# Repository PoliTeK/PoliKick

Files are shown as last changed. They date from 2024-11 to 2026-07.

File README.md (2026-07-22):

<h1 align="center">
	<br>
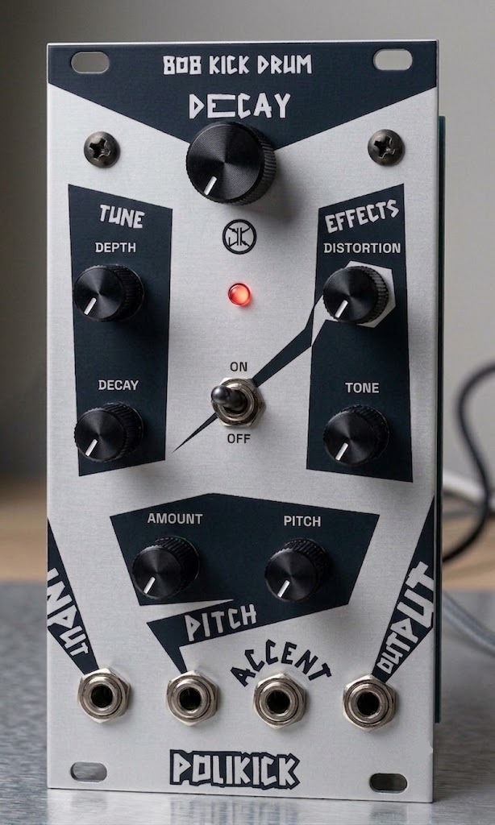
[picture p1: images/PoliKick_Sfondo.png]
		
	<br>
		PoliKicK
	<br>
</h1>

<h4 align="center"> PoliKick is an analog Eurorack kick drum inspired by the legendary <a href="https://en.wikipedia.org/wiki/Roland_TR-808">TR-808</a>. Based on the <a href="https://www.ericasynths.lv/shop/diy-kits-1/edu-diy-kick-drum/">EDU DIY Kick Drum</a> by  <a href="https://www.ericasynths.lv">Erica Synths</a>, it adds a selectable distortion stage and an extended note range.

---

<p align="center">
	<a href="#key-features">Key Features</a> •
	<a href="#list-of-components">List of Components</a> •
	<a href="#how-to-use">How To Use</a> •
	<a href="#credits">Credits</a> •
	<a href="#license">License</a>
</p>

## Key Features

- **Eurorack Standard:** Designed for standard +12V/-12V Eurorack power rails with a 10-pin power header.
- **Trigger and CV Control:** Accepts standard modular trigger pulses (5V-10V) and Control Voltage inputs for dynamic parameter modulation.
- **Authentic Circuitry:** Faithful reproduction of the original analog synthesis paths using modern, easily sourced equivalent components.
- **Expanded Sound Design:** Additional parameters exposed on the front panel compared to the original desktop unit.

## Documentation
The complete design process, simulations, acoustic analysis, crossover calculations, measurements, and construction guide can be found inside the <a href="https://github.com/PoliTeK/PoliKick/tree/NewMain/Documents">**documents**</a> folder included in this repository.

# Project Component List

All the components listed below can be easily found and purchased on major electronic component distributors such as Mouser and DigiKey.

## Resistors

*All resistors are through-hole Metal Film (Part Number: `MFR-25FRF52`)*

| Resistor | Value |
| --- | ----- |
| R1 | 470k  |
| R2 | 4.7k  |
| R3 | 47k |
| R4 | 1M |
| R5 | 100k  |
| R6 | 14k |
| R7 | 33k |
| R8 | 100k  |
| R9 | 100k  |
| R10 | 22k |
| R11 | 120k  |
| R12 | 39k |
| R13 | 100k  |
| R14 | 1k |
| R15 | 1k |
| R16 | 1k |
| R17 | 18k |
| R18 | 1M |
| R19 | 100k  |
| R20 | 10k |
| R21 | 2k |
| R22 | 330 |
| R23 | 10 |
| R24 | 10 |

## Capacitors

| Capacitor | Value | Part Number |
| --- | --- | --- |
| C1 | 15 nF | `MMK5153K50`  |
| C2 | 15 nF | `MMK5153K50`  |
| C3 | 10 nF | `C430C106K3R` |
| C4 | 68 nF | `C320C683J5R` |
| C5 | 5.6 nF  | `MMK5332K50`  |
| C6 | 220 nF  | `MMK5224J50`  |
| C7 | 47 µF | `ESH476M050AG3KA` |
| C8 | 100 nF  | `K104K15X7RF53L2` |
| C9 | 47 µF | `ESH476M050AG3KA` |
| C10 | 100 nF  | `K104K15X7RF53L2` |

## Diodes

| Diode | Characteristics  | Part Number |
| --- | --- | --- |
| D1 - D7 | Small Signal | `1N4148` |
| D8 - D9 | Schottky Barrier | `1N5819` |
| DS1 | Through Hole LED | `LTL-1CHYE` |

## ICs and Transistors

| Component  | Characteristics | Part Number |
| --- | --- | --- |
| U1 | Quad Low-Noise OP Amp | `TL074CN` |
| Q1, Q3, Q4 | NPN Transistor | `BC548B` |
| Q2, Q5 | PNP Transistor | `BC558B` |

## Potentiometers

| Designator | Name | Value | Part Number |
| --- | --- | --- | --- |
| A1 | AmpDeca | 50k, log  | `PTV09A-5025F-A503` |
| A2 | Distortior| 100k, log | `PTV09A-4030F-A104` |
| B1 | Pitch | 100k | `PTV09A-4025F-B104` |
| B2 | Tone | 50k | `PTV09A-4025F-B503` |
| B3 | TuneDeca  | 100k | `PTV09A-4025F-B104` |
| B4 | TuneDept  | 10k | `PTV09A-4025F-B103` |
| B5 | PitchAmo  | 100k | `PTV09A-4025F-B104` |

## Connectors and Switches

| Component | Description | Part Number  |
| --- | --- | --- |
| Connector | Power Header | `TSW-105-07-T` |
| Connector | IC soket | `1-2199298-3`  |
| IN1-Gate | 3.5 mm Stereo Jack | `SJ3-35052B` |
| IN2-AccentCV | 3.5 mm Stereo Jack | `SJ3-35052B` |
| IN3-PitchCV  | 3.5 mm Stereo Jack | `SJ3-35052B` |
| OUT1 | 3.5 mm Stereo Jack | `SJ3-35052B` |
| SW1 | Toggle Switch | `MN12SS4G03` |

## Mechanical Hardware

| Component | Description | Size / Value |
| --- | --- | --- |
| Screws | Machine Screws | M3 |
| Standoffs | Hex Standoffs / Spacers | M3, 1.5cm |

## How To Use

### Hardware Installation

To install the module in your Eurorack system:
1. Ensure your Eurorack case is completely powered off.
2. Connect the 10-pin end of the ribbon cable to the header on the module's PCB. Pay strict attention to the orientation: the **red stripe** on the cable must align with the **-** marking on the PCB.
3. Connect the 16-pin end of the cable to the bus board of your case (red stripe matching -12V).
4. Secure the module to the rails using M3 screws before powering on the case.

### LTspice Simulation

To simulate the analog behavior of the  circuitry, we used LTspice.

- Inside the `Simulation` folder, you will find the `PoliKick.asc` files containing the core voice circuits.
- The trigger inputs in the simulation are modeled using a `PULSE` voltage source configured to  mimick a standard sequencer trigger.
- Run the `.tran` command to observe the envelope generation and the audio output transient response.
- You can adjust the `.step param` commands on the simulated potentiometers to test the range of the front panel controls.

## Credits

Circuit analysis and schematic references based on the [EDU DIY Kick Drum](https://www.ericasynths.lv/shop/diy-kits-1/edu-diy-kick-drum/) by Erica Synths, which originates from the classic Roland TR-808 service manual.

## License

[MIT](https://choosealicense.com/licenses/mit/)

---

<p align="center">
	<a href="mailto:info.politek23@gmail.com">E-Mail</a> •
	<a href="https://www.instagram.com/politek_music">Instagram</a> •
	<a href="https://t.me/+dLKMAwzNmQYxNzM0">Telegram Community</a>
</p>

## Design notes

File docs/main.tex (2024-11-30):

\documentclass{article}

% Useful packages
\usepackage{amsmath}  % improve math presentation
\usepackage{amssymb}
\usepackage{amsthm}
\usepackage[italian]{babel}
\usepackage{cancel}
\usepackage{caption}
\captionsetup{labelfont=bf, font=footnotesize}
\usepackage{circuitikz}
\usepackage{cite} % takes care of citations
\usepackage{enumitem}
\usepackage[final]{hyperref} % adds hyper links inside the generated pdf file
\hypersetup{
	colorlinks=true,       % false: boxed links; true: colored links
	linkcolor=blue,        % color of internal links
	citecolor=blue,        % color of links to bibliography
	filecolor=magenta,     % color of file links
	urlcolor=blue         
}
\usepackage[utf8]{inputenc}
\usepackage[letterpaper,top=2cm,bottom=2cm,left=3cm,right=3cm,marginparwidth=1.75cm]{geometry}
\usepackage{graphicx} % takes care of graphic including machinery
\usepackage{placeins} % better float control
\usepackage{siunitx}
\sisetup{
    sticky-per,
    per-mode=power,
    exponent-product=\cdot,
    forbid-literal-units,
    inline-per-mode=power,
    display-per-mode=fraction,
    uncertainty-mode=separate,
    output-decimal-marker={,}
}
\usepackage{standalone}
\usepackage{subcaption}
\usepackage{tabularx} % extra features for tabular environment

%

\newcommand{\var}[2]{#1_\mathrm{#2}}
\DeclareMathOperator{\ustep}{u}

\theoremstyle{definition}
\newtheorem{example}{Esempio}

%

\title{PoliKick}
\author{Politek}

\begin{document}
\maketitle

\numberwithin{figure}{section}
\numberwithin{equation}{section}

\section{Introduzione}
In questo documento si studia il comportamento dei diversi blocchi che compongono il kick.

\section{Componenti}

\subsection{Gate to Trigger}

\subsubsection{Analisi}
Per cominciare, studiamo il primo blocco del circuito.
La tensione d'ingresso \(v_i\) è un segnale che proviene da un sequencer, pertanto sarà formato da una sequenza di porte rettangolari ("gate").
L'obiettivo di questa sezione è condizionare il segnale in modo che sia utilizzabile dal circuito oscillatore.

\begin{figure}[ht]
    \centering
    \input{circuits/gate_to_trigger.tex}
    \label{fig:gate-to-trigger}
    \caption{Gate to Trigger}
\end{figure}

Ignoriamo inizialmente il diodo. Il segnale \(v_i\) viene immediatamente filtrato da un filtro RC passa-alto, pertanto la tensione \(v_+\) assume la caratteristica forma esponenziale ad ogni transizione di \(v_i\).
È utile introdurre il diodo \(D\) perché alcuni op-amp soffrono di un effetto chiamato "phase inversion" se la tensione ai terminali diventa eccessivamente negativa; il compito del diodo è di bloccare la tensione su \(v_+\) ad un valore fisso durante la fase di discesa del segnale \(v_i\) (figura \ref{fig:gate-to-trigger-condizionamento}).
\\

L'op-amp è nella configurazione di comparatore non invertente senza isteresi:
%
\begin{align*}
    v_o &= \begin{cases}
        +\var{V}{AL}, & v_A > \var{V}{REF} \\
        -\var{V}{AL}, & v_A < \var{V}{REF} \\
    \end{cases}
    &
    \var{V}{REF} &= k \var{V}{AL}
    &
    k \triangleq \frac{R_a}{R_a + R_b}
\end{align*}

La frequenza di taglio del filtro passa-alto è \(f_0 = \frac{1}{2 \pi \tau}\), dove \(\tau = RC\).
Durante il transitorio in fase di salita del segnale \(v_i\), si ha \(v_A > \var{V}{REF}\) solo per un breve intervallo di tempo \(\Delta t\).
In questo intervallo l'uscita del comparatore è \(\var{V}{AL}\).
%
\begin{figure}[htp]
    \centering
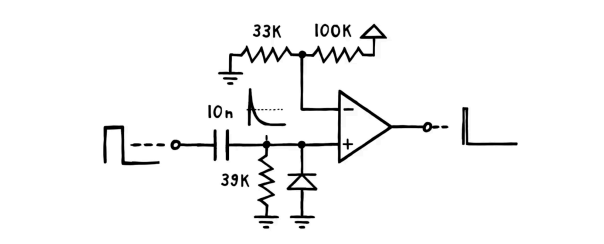
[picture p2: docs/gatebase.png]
     
    \caption{Condizionamento del segnale}
    \label{fig:gate-to-trigger-condizionamento}
\end{figure}
\\
Esaminiamo uno di questi transitori:
\begin{align}
    v_A(t) > \var{V}{REF} & \implies
    V_I e^{-t/\tau} \ustep(t) > \var{V}{REF} = k \var{V}{AL} \geq 0 \nonumber \\
    & \implies 0 < t < \tau \log\frac{V_I}{k \var{V}{AL}} \triangleq \Delta t
    \label{eq:trigger-dt}
\end{align}

Affinché il funzionamento del circuito sia corretto è necessario che l'op-amp abbia uno slew rate sufficientemente alto:
\begin{equation*}
    S_R \gg \frac{2 \var{V}{AL}}{\Delta t}
\end{equation*}

La presenza dell'op-amp garantisce un'impedenza d'uscita \(\var{R}{out} \approx 0\).

\subsubsection{Dimensionamento}
È necessario che la costante di tempo \(\tau\) sia sufficientemente piccola rispetto alla durata \(T\) del gate.
Scegliamo prima il valore di \(\Delta t\), da cui dipende il funzionamento del blocco oscillatore.
Imponiamo quindi \(5 \tau \le T\)

\begin{example}
    Si sceglie \(\Delta t = \tau = T/10\), dunque:
    \begin{align*}
        &\cancel{\tau} \log\frac{V_I}{k \var{V}{AL}} = \cancel{\Delta t} \implies
        V_I = e \cdot k \var{V}{AL} \implies
        k = \frac{R_a}{R_a + R_b} = \frac{V_I}{e \var{V}{AL}} \\
        &\tau = RC \implies C = \tau/R = \frac{T}{10R}
    \end{align*}
\end{example}

\subsection{Accent Control Voltage}

\subsubsection{Analisi}

Il secondo blocco che esamineremo è l'\emph{Accent CV}, che permette di modificare l'entità dell'impulso in uscita dal blocco precedente attraverso una tensione di controllo \(v_A\)
(figura \ref{fig:accent-cv}).
La tensione \(v_A\) assume un valore compreso tra \qty{0}{\volt} e \qty{5}{\volt}. \\

\begin{figure}[ht]
    \centering
    \input{circuits/accent_cv.tex}
    \caption{Accent CV}
    \label{fig:accent-cv}
\end{figure}

Innanzitutto osserviamo che \(T_1\) non può entrare in saturazione perché \(\var{V}{CB,1} = -v_A \le \qty{0}{\volt}\), pertanto la giunzione collettore-base non può essere in conduzione.
Poiché la tensione in ingresso \(v_i\) è la tensione d'uscita del gate to trigger, per analizzare il funzionamento di questo circuito consideriamo due casi:

\begin{enumerate}
    \item Impulso, uscita del comparatore alta (\(v_i = +\var{V}{AL}\))
    \item Uscita del comparatore bassa (\(v_i = -\var{V}{AL}\))
\end{enumerate}

Nel primo caso ipotizziamo \(T_1\) e \(T_2\) in linearità, e verifichiamo che quest'ipotesi sia compatibile con i risultati.
Allora \(T_2\) è in configurazione di collettore comune e riporta, con un piccolo offset, la tensione che riceve sulla base (\(v_B\)).
Invece \(T_1\), siccome la giunzione emettitore-base è in conduzione, riporta \(v_A\) sul suo emettitore;
ai fini di questa analisi si comporta come un generatore di tensione di valore \(v_A + \var{V}{EB,1,on}\).
Ipotizzando che la corrente di base di \(T_2\) sia trascurabile, otteniamo per \(v_B\) la seguente espressione:
%
\begin{equation}
    v_B = \frac{R_I \parallel R_B}{R_E + R_I \parallel R_B} \left(v_A + \var{V}{EB,1,on} \right) +
    \frac{R_E \parallel R_B}{R_I + R_E \parallel R_B} \var{V}{AL}
\end{equation}
%
L'uscita del blocco è \(v_o = v_B - \var{V}{BE,2,on}\).
\\

Nel secondo caso \(v_i = -\var{V}{AL}\) e risulta \(v_B < 0 \); entrambi i transistor sono in interdizione e l'uscita del blocco vale \(v_o = \qty{0}{\volt}\).

% TODO: inserire grafici dell'andamento di v_B

\subsection{T-Oscillator}
\subsubsection{Comportamento qualitativo nel dominio tempo}
\begin{figure}[ht]
    \centering
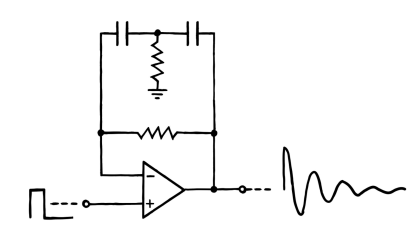
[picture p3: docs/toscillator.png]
     
    \label{fig:Toscillator}
\end{figure}

Il Toscillator è un circuito costituito da un solo amplificatore operazionale, due resistenze e due condensatori. Insieme formano un oscillatore a onda sinusoidale piuttosto strano che necessita di essere avviato con un impulso di tensione per iniziare a oscillare.
Tuttavia, anche quando avviato, non continuerà a oscillare come fanno gli altri oscillatori, ma l'ampiezza calerà rapidamente fino a scomparire del tutto. Questo comportamento non è ideale per la maggior parte degli scenari, ma è perfetto per il nostro.Vediamo come funziona.

\begin{figure}[ht]
    \centering
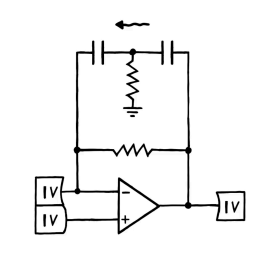
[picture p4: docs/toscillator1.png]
     
    \label{fig:Toscillator1}
\end{figure}

 Supponiamo che la tensione all'ingresso non invertente dell'opamp salti rapidamente da 0 a 1 volt. Per raggiungere uno stato di equilibrio, l'opamp cercherà di aumentare la tensione all'ingresso invertente fino a 1 volt anch'esso ( ricorda v+ = v- in un opamp).
 Per farlo, aumenterà inizialmente la sua tensione di uscita a 1 volt. Questo funzionerà all'inizio, poiché tale tensione attraversa direttamente i due condensatori e raggiunge così l'ingresso invertente.
 Tuttavia, a causa della presenza di una resistenza verso terra tra i due condensatori, vedremo una corrente che defluisce dal primo condensatore, il che significa che la tensione applicata al secondo condensatore, e successivamente all'ingresso invertente, diminuirà.

\begin{figure}[ht]
    \centering
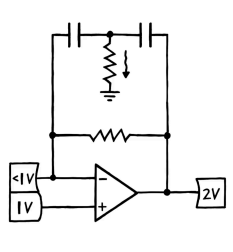
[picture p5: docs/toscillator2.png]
     
    \label{fig:Toscillator2}
\end{figure}

Per compensare, l'op-amp aumenterà la sua tensione di uscita, ma facendo ciò, ancora più corrente verrà spremuta fuori dal primo condensatore, costringendo l'op-amp a spingere ancora di più.
Questo continuerebbe fino a quando l'op-amp raggiunge la tensione di alimentazione superiore, se non fosse per la resistenza di collegamento in retroazione.
Man mano che l'op-amp spinge sempre più forte, quella resistenza permette una piccola corrente di caricare il secondo condensatore dall'altro lato.
A un certo punto, questo processo aggiungerà più tensione sulla sinistra di quanta ne perderemo a destra, facendo sì che l'intero meccanismo si inverta.

\begin{figure}[ht]
    \centering
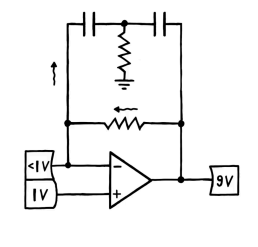
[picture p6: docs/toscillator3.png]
     
    \label{fig:Toscillator3}
\end{figure}

L'op-amp inizierà a ridurre la sua tensione di uscita per cercare di correggere, ma il problema è che ciò sottrarrà corrente dal primo condensatore e successivamente dal lato terra, aumentando la tensione tra i due condensatori e quindi all'ingresso invertente, il che costringerà l'op-amp a ridurre ulteriormente la sua tensione di uscita.
Alla fine raggiungeremo di nuovo un punto critico dove il meccanismo si invertirà, ma questa volta a una tensione di uscita leggermente inferiore.
Questo accade perché ad ogni ciclo di carica e scarica perdiamo un po' del momento iniziale. 

\begin{figure}[ht]
    \centering
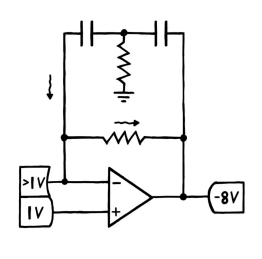
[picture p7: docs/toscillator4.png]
     
    \label{fig:Toscillator4}
\end{figure}

Il circuito si comporta un po' come un pendolo, e quindi l'uscita prodotta è un'onda sinusoidale che oscilla attorno alla tensione dell'ingresso non invertente con un'ampiezza in continua diminuzione, che dovrebbe già suonare molto simile a un suono di grancassa se la frequenza è abbastanza bassa.
Per assicurarsi che lo sia, dobbiamo scegliere la giusta combinazione di valori per i condensatori e le resistenze.
Questo è un po' complicato, poiché tutti questi valori influenzano sia la frequenza che il decadimento contemporaneamente.
Nel circuito originale della grancassa dell'808, Roland utilizzava una resistenza di collegamento da 1 Megaohm, una resistenza verso terra da 51k e due condensatori da 15 nanofarad, ottenendo una frequenza di oscillazione di 50 hertz con un decadimento molto rapido.
Usiamo questi valori come punto di partenza. 

\subsubsection{Dominio frequenza}

Il circuito in retroazione puo' essere visto come un filtro elimina banda  (notch filter) 
che quando viene inserito nella retroazione di un amplificatore operazionale, trasforma il sistema in un filtro passa-banda. Utilizzando le equazioni per la rete a T di ponte, si possono trovare la frequenza centrale e il fattore di qualità del filtro in base ai valori combinati di resistenze e condensatori.

\begin{equation}
    f = \frac{1}{2 \pi\sqrt{R_1 R_2 C_1 C_2}}
\end{equation}

\begin{equation}
    Q = \frac{\sqrt{\frac{R_1}{R_2}}}{\sqrt{\frac{C_1}{C_2}} + {\frac{C_2}{C_1}}}
\end{equation}

Per utilizzare il filtro passa-banda come oscillatore, devono essere soddisfatte due condizioni: il cambiamento di fase intorno al loop dell'amplificatore operazionale deve essere un multiplo di 360 gradi (incluso 0 gradi) e ci deve essere un guadagno sufficiente.
Nel circuito del filtro a T di ponte, l'uscita dell'amplificatore operazionale ha uno sfasamento di 0 gradi alla frequenza centrale. Pertanto, se calcoliamo una frequenza centrale per una certa frequenza dell'oscillatore desiderata, possiamo scegliere i valori corretti dei componenti per ottenere quella frequenza centrale, che ci darà uno sfasamento di 0 gradi a quella frequenza. 

\begin{figure}[htp]
    \centering
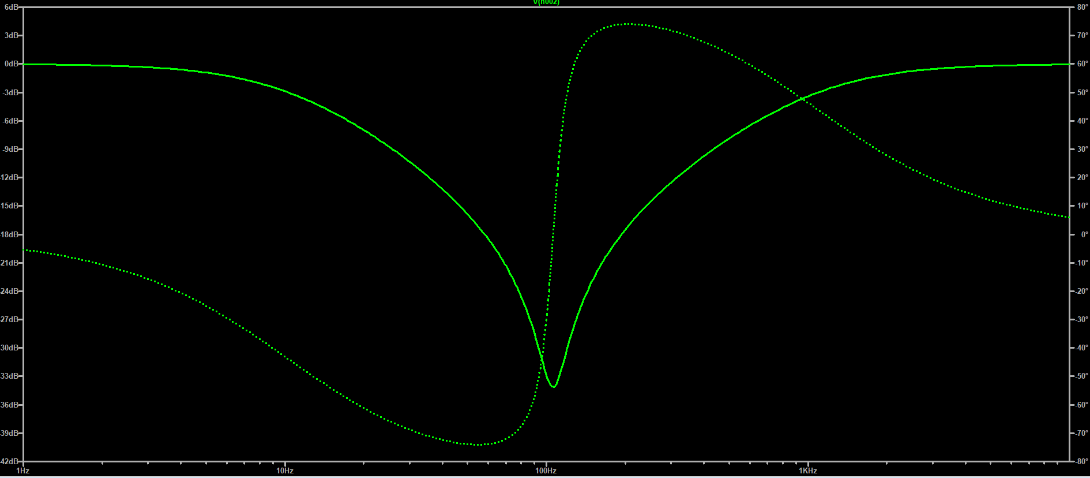
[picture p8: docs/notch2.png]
     
    \caption{notch filter}
    \label{fig:Notch-filter}
\end{figure}

\begin{figure}[htp]
    \centering
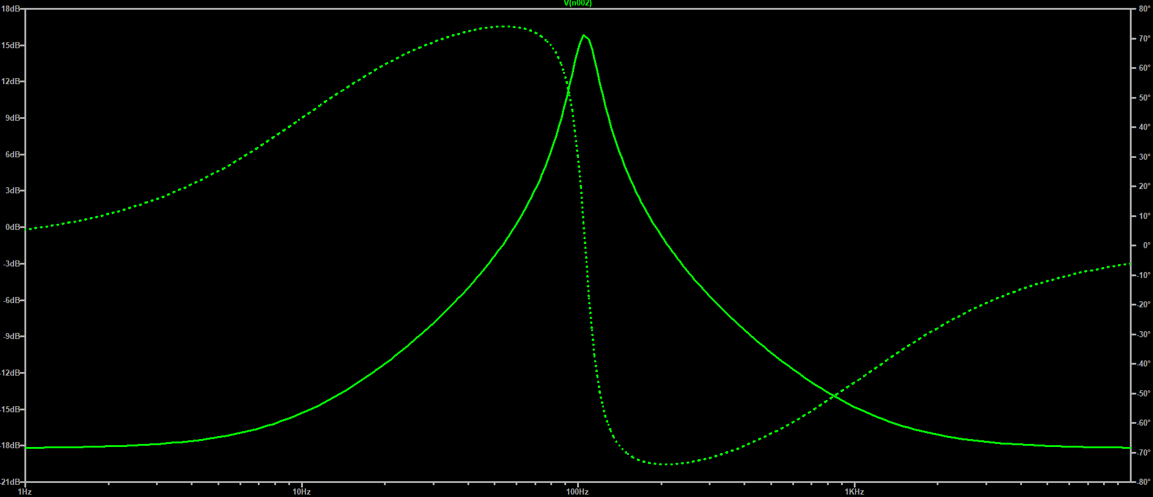
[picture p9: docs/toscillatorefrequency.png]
     
    \caption{T-oscillator}
    \label{fig:Toscillator-plot}
\end{figure}

\end{document}

//Il blocco base consiste in un filtro passa alto e un comparatore (tensione soglia 3V). 
Quando applichiamo un onda quadra  il condensatore si carica fino a 5 V e poi tramite la resitenza al ground si scarica. La velocita' di scarica dipende dalla capacita del condensatore piu e' alta piu' tempo ci impiega. Quando la tensione sulla resitenza e' maggiore di quella del morsetto invertente 3V l'uscita dell'opamp va al max ovvero 12 V, mentre se minore a -12V (ricorda alimentazione).
Avendo bisogno di un impulso in uscita andiamo a prendere un condensatore con capacita piccola. Di conseguenza l'intervallo di tempo dove la tensione sulla resistenza e' maggiore di 3V sara' breve e quindi avremo in uscita un impulso.//

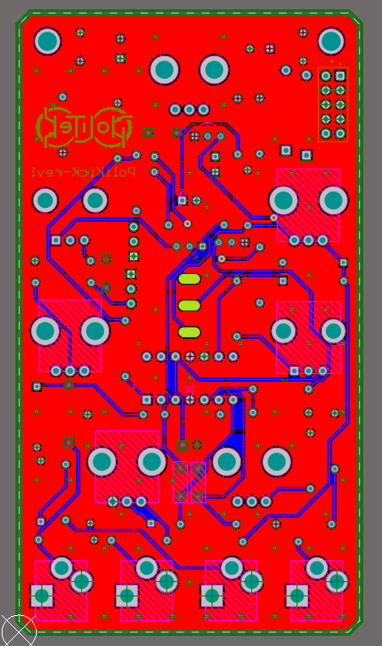
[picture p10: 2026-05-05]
images/PCB_Front.png

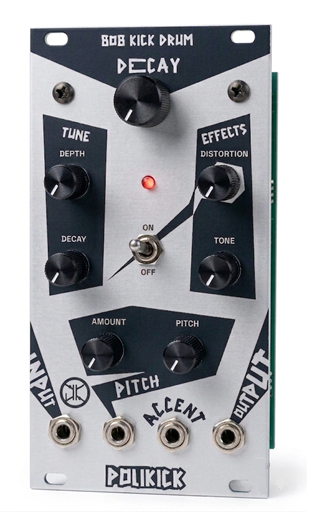
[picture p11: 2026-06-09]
images/PoliKick_MezzoPRofilo.png

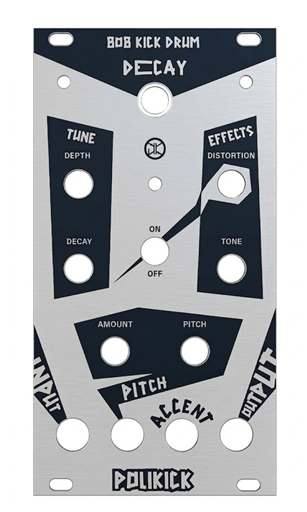
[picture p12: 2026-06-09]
images/PoliKick_Dritto.png

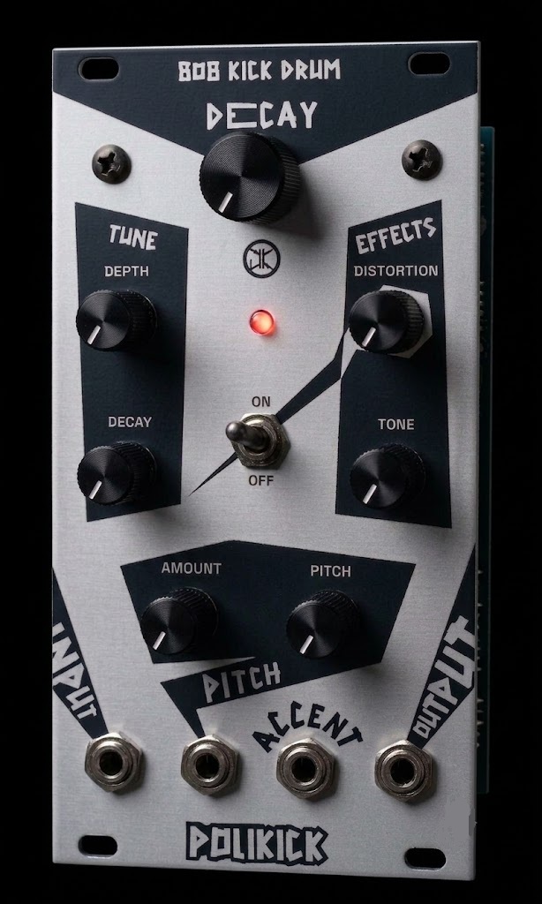
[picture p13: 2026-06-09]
images/PoliKick_MezzoPRofilo_Nero.png

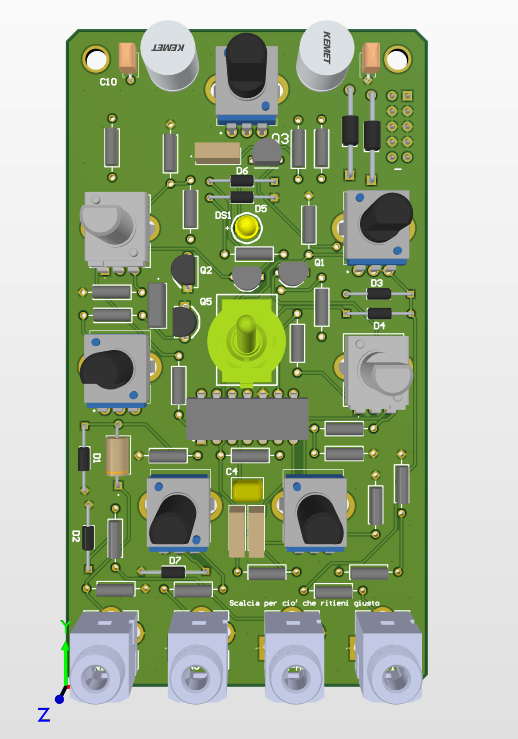
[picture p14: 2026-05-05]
images/PCB_3D.png

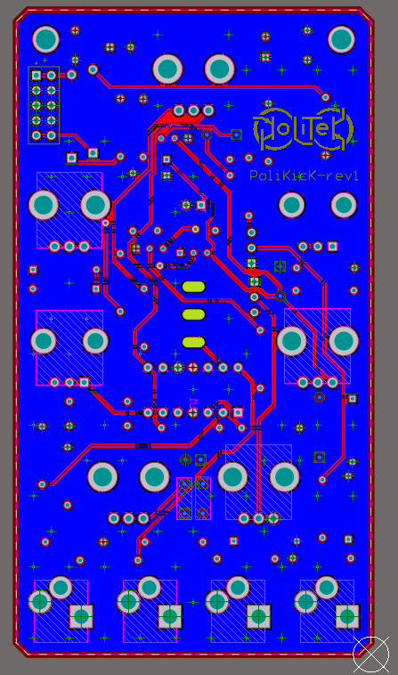
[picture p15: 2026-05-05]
images/PCB_Back.png

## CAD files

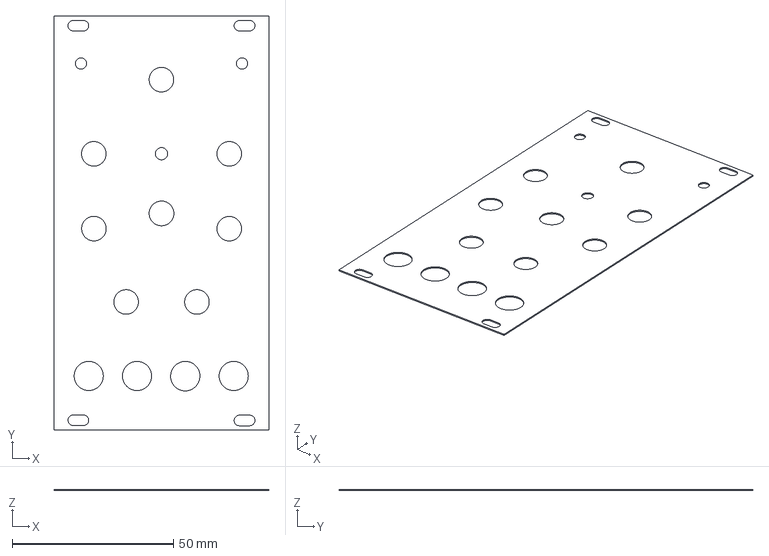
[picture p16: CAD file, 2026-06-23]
Front Panel/PoliKick_FrontPanel-rev1.step
66.6 x 128.5 x 0.411 mm

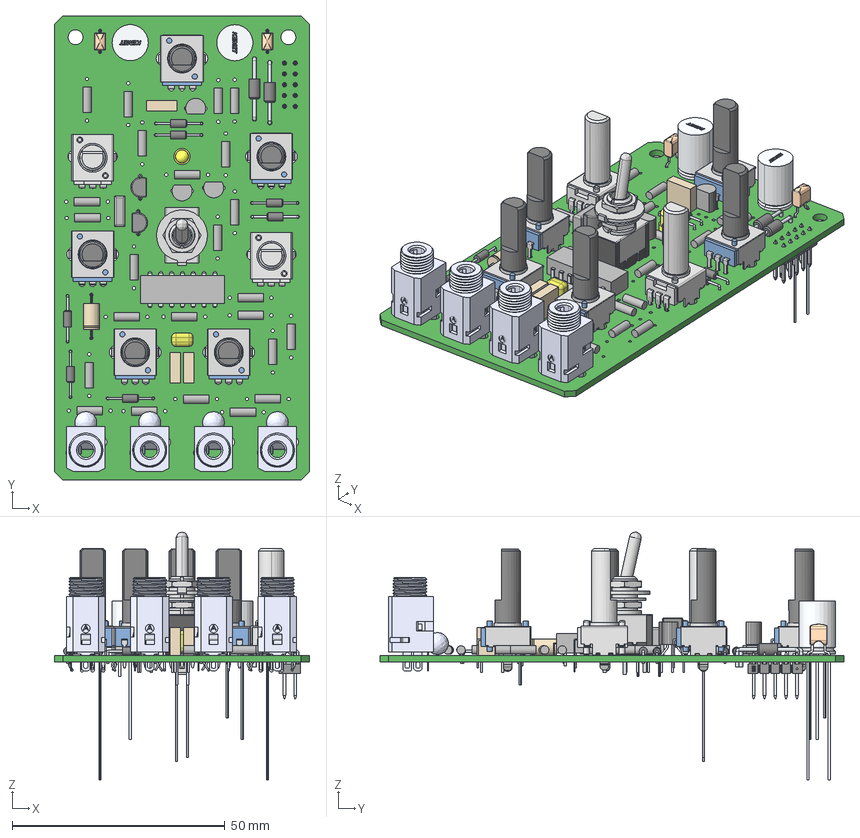
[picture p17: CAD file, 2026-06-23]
PCB/PoliKicK_PCB_rev-1.step
60.0 x 109.0 x 58.2 mm
Extruded x 48
M20121SS4W01-switch
M201S4M201-bushing
AT513M x 2
AT507M
AT509
M201201-terminals
M20S-toggles
TSW-102-08-G-D_body
logo
T-1S6-08-TSW-1-08-2-D x 10
CFR_RB3_7.2X6.5X2.5_L7.2H6.5T2.5S5LL5F0.5
C320C683J5R5TA

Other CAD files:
Front Panel/PoliKick-rev2_3D.step
Front Panel/PoliKick-rev2_Scocca.DXF
Front Panel/PoliKick_FrontPanel_rev1.DXF

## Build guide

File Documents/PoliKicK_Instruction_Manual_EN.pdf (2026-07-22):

# INSTRUCTION MANUAL

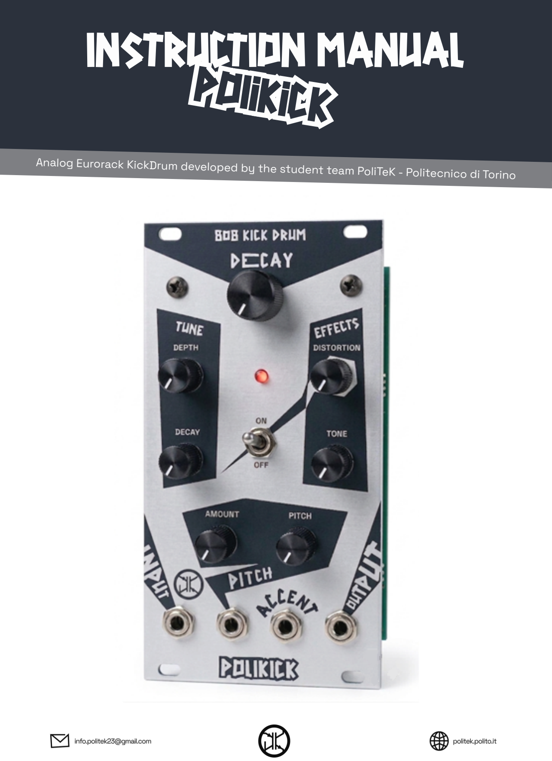
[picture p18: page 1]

Analog Eurorack KickDrum developed by the student team PoliTeK - Politecnico di Torino

# PoliKicK PoliKicK PoliKicK

# INTRODUCTION

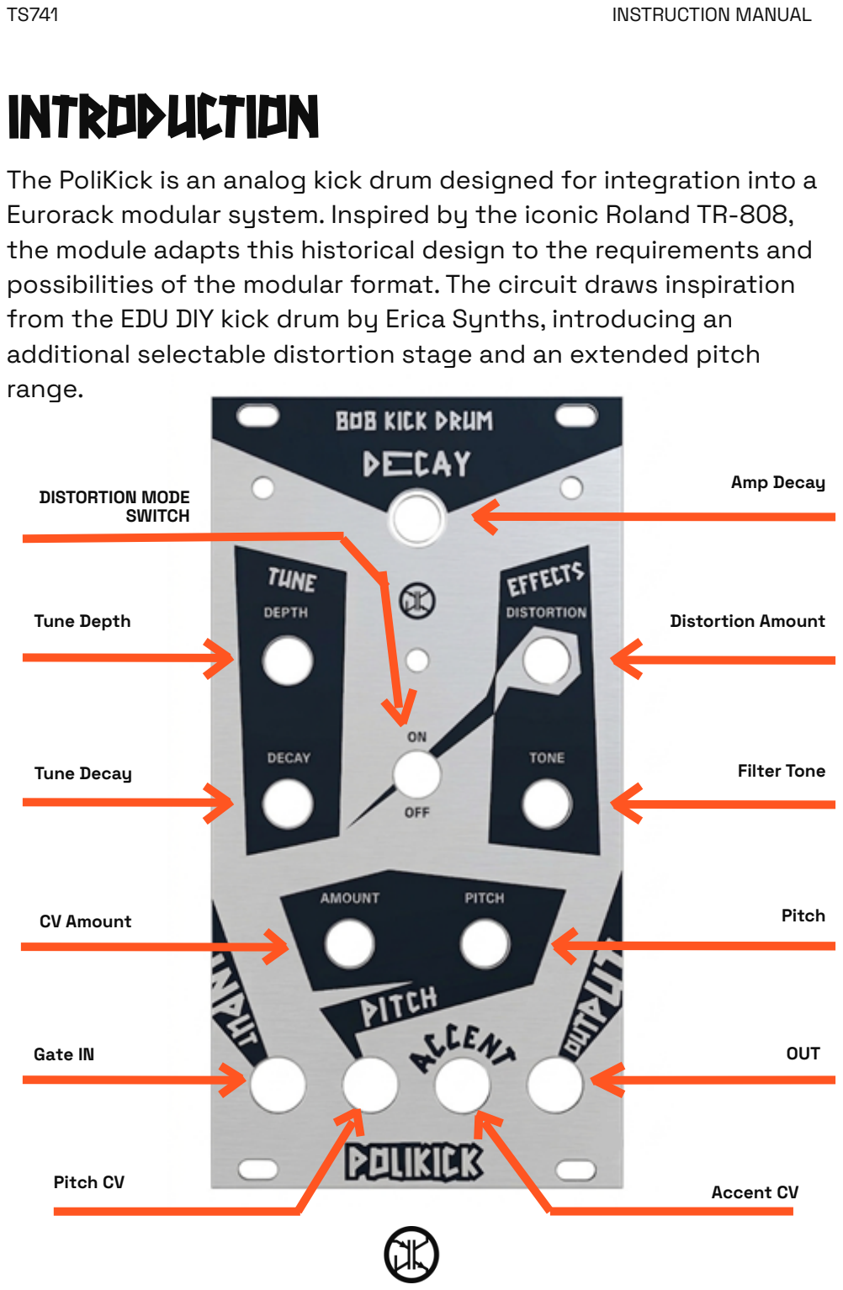
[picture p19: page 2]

OUT

Accent CV

Gate IN

The PoliKick is an analog kick drum designed for integration into a Eurorack modular system. Inspired by the iconic Roland TR-808, the module adapts this historical design to the requirements and possibilities of the modular format. The circuit draws inspiration from the EDU DIY kick drum by Erica Synths, introducing an additional selectable distortion stage and an extended pitch range.

TS741 | INSTRUCTION MANUAL

DISTORTION MODE
SWITCH

Tune Depth

Tune Decay

CV Amount | Pitch Filter Tone

Distortion Amount

Pitch CV

Amp Decay

# HARDWARE AND MATERIALS

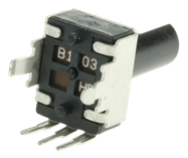
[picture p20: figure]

PCB

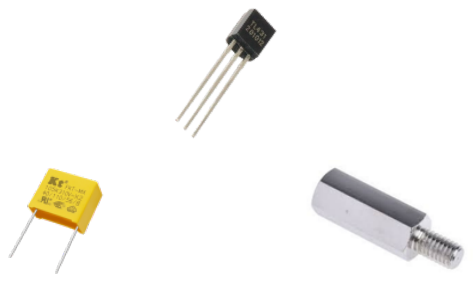
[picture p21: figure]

FRONT PANEL

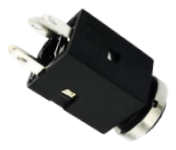
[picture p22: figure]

Electronic
Components

M3 SCREWS
AND NUTS
1.5CM
STANDOFFS

The components required to build the PoliKick include very common resistor values (E12 series), transistors, op-amps, and capacitors. You will likely already have most of these
components available in your laboratory, but the complete Bill of Materials (BOM) can be found in our GitHub repository (https://github.com/PoliTeK/PoliKicK).
These components will be soldered onto the PCB. You can find the manufacturing print files in a dedicated folder within the repository to have them manufactured. Using the files provided in the same repository, it is also possible to have the front panel manufactured in FR-4 (the same material used for printed circuit boards). This solution allows you to obtain a solid, professional front panel while producing both the board and the front interface in a single order.

First, assemble the PCB by soldering all electronic components. It is recommended to solder the smaller components first, such as resistors and capacitors, and solder the connectors, potentiometers, and the switch only at the very end.
The power connector must be soldered onto the back of the board, meaning the opposite side relative to all other components.
During assembly, pay close attention to polarity: diodes, electrolytic capacitors, and the LED have a mandatory insertion direction.
Align the cathode band of the diodes exactly as drawn on the PCB. Align the side stripe of the electrolytic capacitors with the round pad.
Align the dots on the Op-Amp; solder the sockets first, and then insert the Op-Amp into them.
Align the leads of the LED as drawn on the PCB (longer lead to the +).
The red power LED should be soldered last so it can be easily aligned with the front panel hole.

# ASSEMBLY

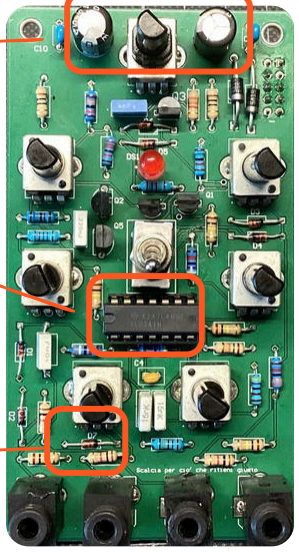
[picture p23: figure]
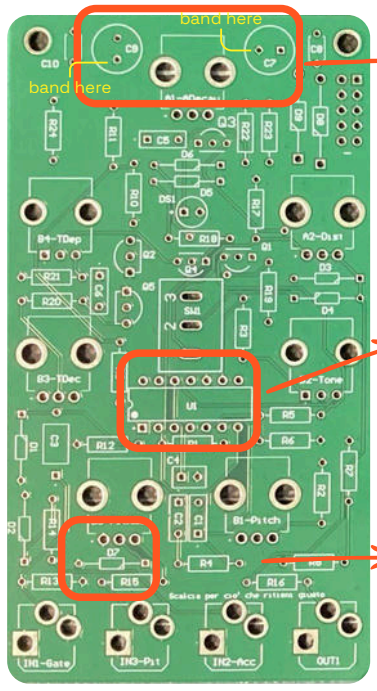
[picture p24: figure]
band here

DOT

# ASSEMBLY

Once the PCB soldering is complete, it is time to attach the board to the front panel. Place the panel over the circuit, ensuring that the holes are perfectly aligned with the potentiometers, jacks, switch, and LED. To secure everything firmly, screw the nuts for the audio jacks and the switch into their respective positions. Finally, use the screws, nuts, and standoffs in the designated PCB holes to tighten the structure and ensure maximum mechanical stability for the module. To conclude the assembly, push the potentiometer knobs onto the shafts.

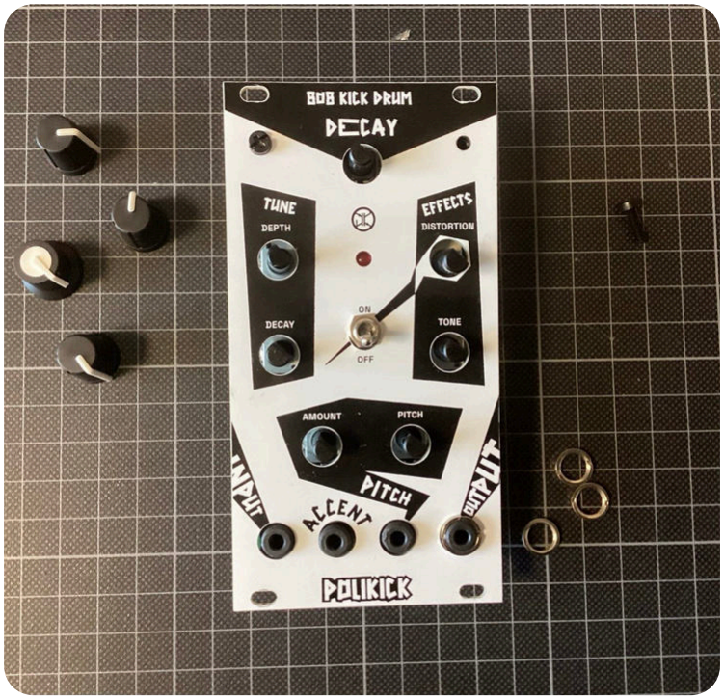
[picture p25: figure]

# ASSEMBLY

The PoliKick is now complete and ready to be mounted into your Eurorack case; follow these steps for a safe installation:
Turn off the power: Before making any connections, ensure that the case power supply is turned completely off and disconnected from the mains electricity.
Connect the ribbon cable: To power the module, you must use a standard ribbon cable. Plug it into the connector on the back of the PCB, paying strict attention to the polarity by aligning the red stripe of the cable with the "-" indicator printed on the silkscreen.
Connect to the bus board: Insert the opposite end of the ribbon cable into the power distribution bus board of your case, verifying once again that the red stripe is correctly oriented toward the -12V rail.
Secure the module: Position the PoliKick into the desired slot and screw the front panel onto the rails using the appropriate mounting screws, taking care not to overtighten them to avoid scratching the FR-4 surface.
Power on: Supply power to the system, patch an input signal into the Trigger jack, and turn up the levels to start using your module.

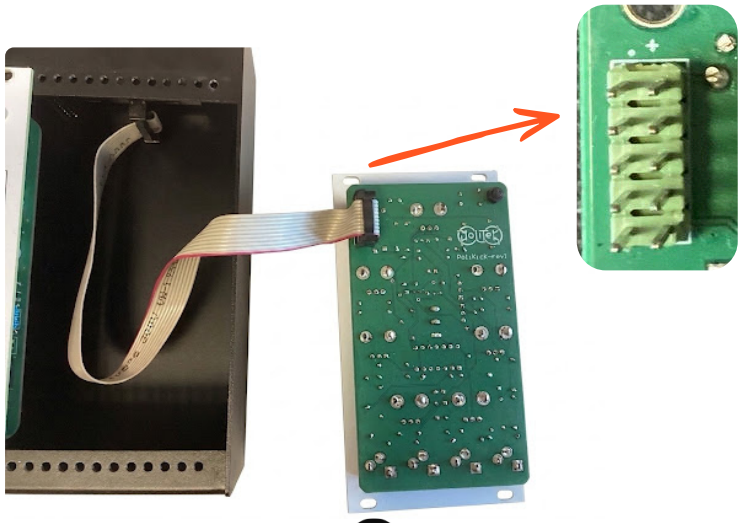
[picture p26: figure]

# TECHNICAL DOCUMENTATION

If you want to learn more or dive deeper into the circuit theory behind this project, you can download our comprehensive technical documentation, where you will find the complete circuit analysis, including all formulas and detailed calculations! Feel free to contact us with any questions, doubts, or if you would like to propose modifications and improvements to the project!

Telegram
Community

Repository
GitHub

Tecnical
Documentation

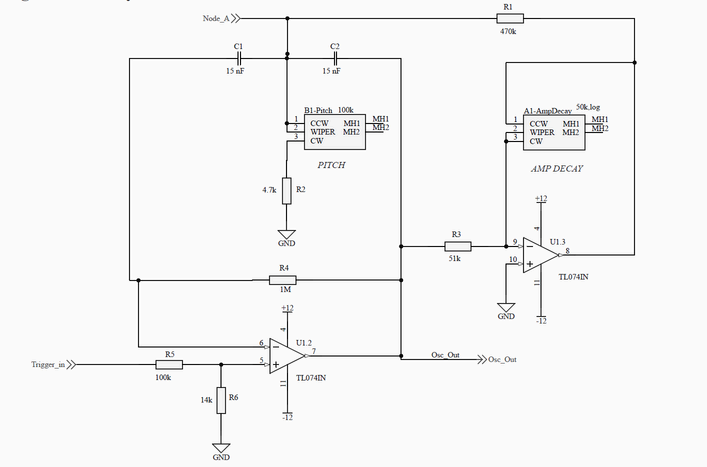
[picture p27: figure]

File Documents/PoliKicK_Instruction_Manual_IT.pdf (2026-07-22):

# INSTRUCTION MANUAL

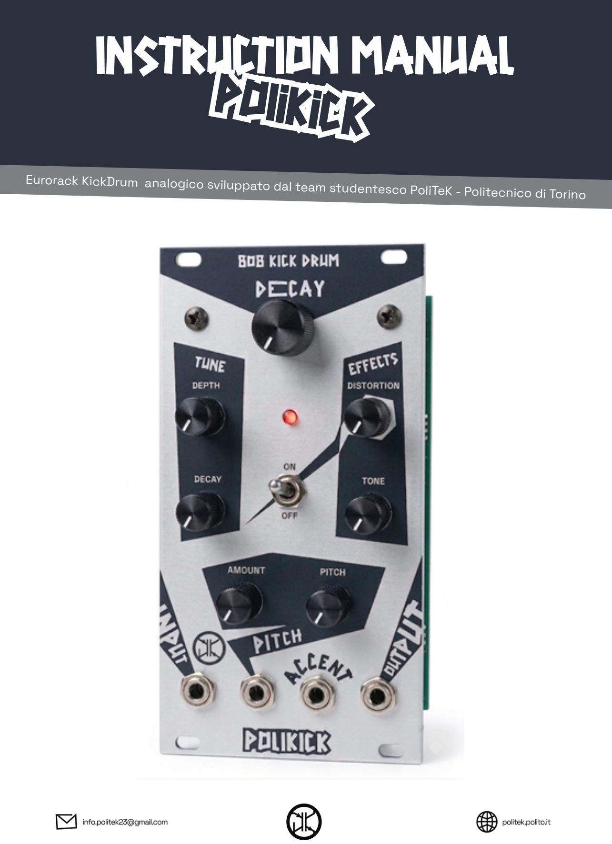
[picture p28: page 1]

Eurorack KickDrum analogico sviluppato dal team studentesco PoliTeK - Politecnico di Torino

# PoliKicK PoliKicK PoliKicK

# INTRODUZIONE

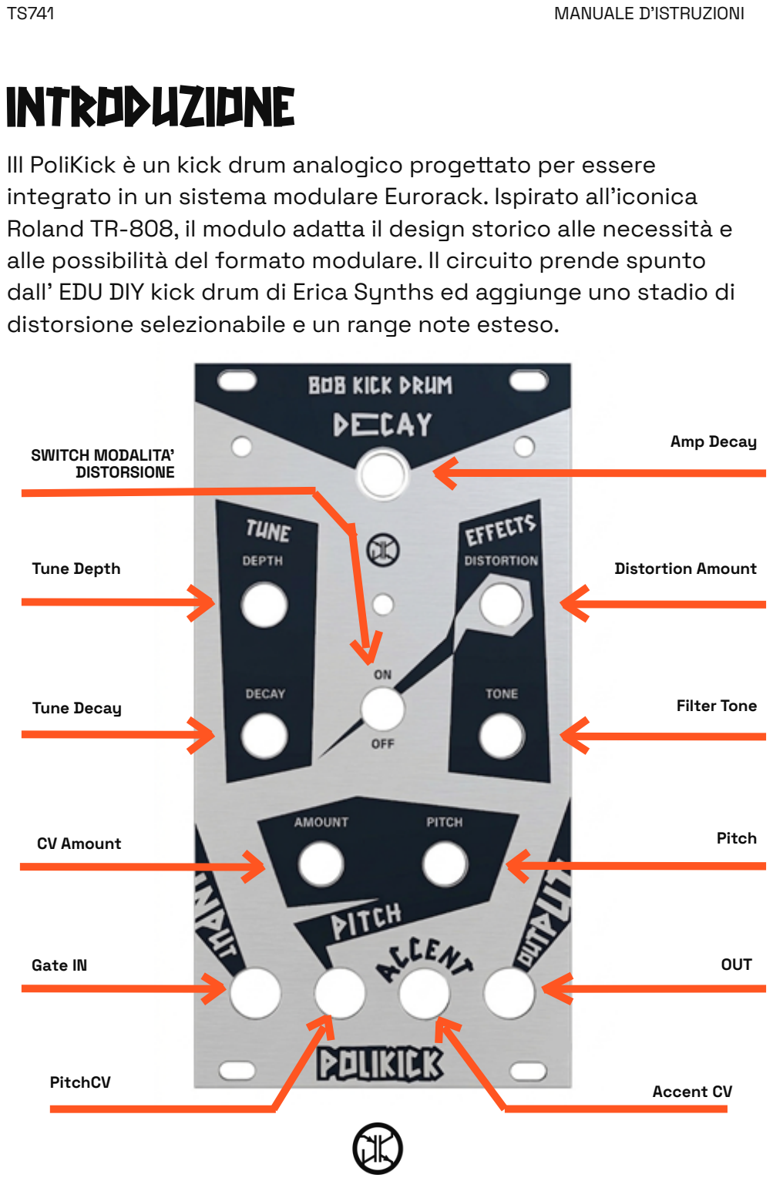
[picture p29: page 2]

OUT

Accent CV

Gate IN

IIl PoliKick è un kick drum analogico progettato per essere integrato in un sistema modulare Eurorack. Ispirato all'iconica Roland TR-808, il modulo adatta il design storico alle necessità e alle possibilità del formato modulare. Il circuito prende spunto dall' EDU DIY kick drum di Erica Synths ed aggiunge uno stadio di distorsione selezionabile e un range note esteso.

TS741 | MANUALE D’ISTRUZIONI

SWITCH MODALITA’
DISTORSIONE

Tune Depth

Tune Decay

CV Amount | Pitch Filter Tone

Distortion Amount

PitchCV

Amp Decay

# HARDWARE E MATERIALI


PCB

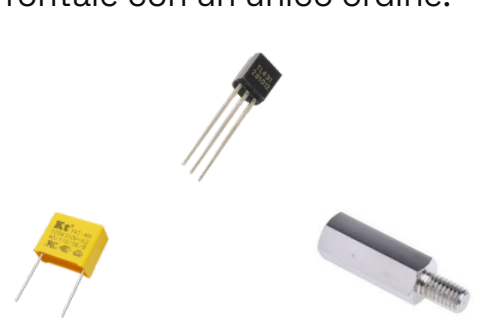
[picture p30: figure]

PANNELLO
FRONTALE


COMPONENTI
ELETTRONICI
VARI

VITI E DADI M3
DISTANZIALI
DA 1.5cm

I componenti necessari per costruire il PoliKicK comprendono dei valori molti comuni di resistori (serie E12), transistor, opamp e condensatori. Probabilmente potresti avere già gran parte dei componenti nel tuo laboratorio, ma puoi trovare la BOM completa nel repository Github (https://github.com/PoliTeK/TS741).

Questi componenti andranno saldati sul PCB, puoi trovare i file di stampa in una cartella dedicata del repository e stamparli presso

Presso gli stessi servizi, utilizzando i file forniti nel repository, è inoltre possibile far realizzare il pannello frontale in FR-4 (lo stesso materiale dei circuiti stampati): questa soluzione ti permette di ottenere un pannello solido e professionale producendo sia la scheda che il frontale con un unico ordine.

Per prima cosa assemblare il PCB saldando tutti i componenti, è conveniente saldare prima tutti i piccoli componenti come resistori e condensatori e saldare solo alla fine i connettori, i potenziometri e lo switch.
il connettore di alimentazione va saldato sul retro della scheda, ovvero sul lato opposto rispetto a tutti gli altri componenti. Durante il montaggio, presta la massima attenzione alla polarità: i diodi, i condensatori elettrolitici e il LED hanno un verso di inserimento obbligato.
Allineare la fascetta dei diodi come disegnato sulla PCB. Allineare la banda laterale degli elettrolitici alla piazzola rotonda. Allineare i puntini dell’ OP-Amp, saldare gli zoccolie ad inserire sopra l’OP-Amp.
Allineare i piedini del LED come disegnato sulla PCB ( piedino lungo al +)
Il LED rosso di accensione va saldato per ultimo per essere facilmente allineato al foro del pannello.

# ASSEMBLAGGIO

band here

DOT

# ASSEMBLAGGIO

Una volta completata la saldatura del PCB, è il momento di unire la scheda al pannello frontale.
Adagia il pannello sopra il circuito, assicurandoti che i fori siano perfettamente allineati con i potenziometri, i jack, switch e LED. Per fissare saldamente il tutto, avvita i dadi dei jack audio e dello switch nei rispettivi alloggiamenti. Infine, utilizza le viti, dadi e distanziali negli appositi fori del PCB per serrare la struttura e garantire la massima stabilità meccanica al modulo.
Per concludere l'assemblaggio inserisci i copripotenziometri.


# ASSEMBLAGGIO

Il PoliKick è ora completato e pronto per essere montato nel case Eurorack; segui questi passaggi per un'installazione sicura:
1.Spegni l'alimentazione: Prima di effettuare qualsiasi collegamento, assicurati che il case sia spento e scollegato dalla rete elettrica. 2.Collega il cavo: Per alimentare il modulo è necessario utilizzare un ribbon cable da 5; inseriscilo nel connettore sul retro del PCB prestando attenzione alla polarità, facendo coincidere la banda rossa del cavo con l'indicazione “

” stampata sulla serigrafia. 3.Collega alla bus board: Inserisci l'estremità opposta del ribbon cable nella scheda di distribuzione dell'alimentazione del tuo case, verificando anche in questo caso che la banda rossa sia orientata correttamente verso i -12V.
4.Fissa il modulo: Posiziona il PoliKick nello slot desiderato e avvita il pannello frontale ai binari utilizzando le apposite viti, prestando attenzione a non stringere eccessivamente per non graffiare la superficie in FR-4.
5.Accensione: Fornisci corrente al sistema, collega un segnale in ingresso al jack di Trigger e alza i livelli per iniziare a utilizzare il modulo.


# DOCUMENTAZIONE TECNICA

Se vuoi saperne di più o approfondire la teoria circuitale dietro questo progetto puoi scaricare la nostra documentazione tecnica in cui puoi trovare tutta l’analisi tecnica del circuito incluse formule e calcoli completi!

Contattaci per qualsiasi dubbio o domanda, o se vuoi proporre delle modifiche o dei miglioramenti al progetto!

Telegram
Community

Repository
GitHub

Documento
Tecnico


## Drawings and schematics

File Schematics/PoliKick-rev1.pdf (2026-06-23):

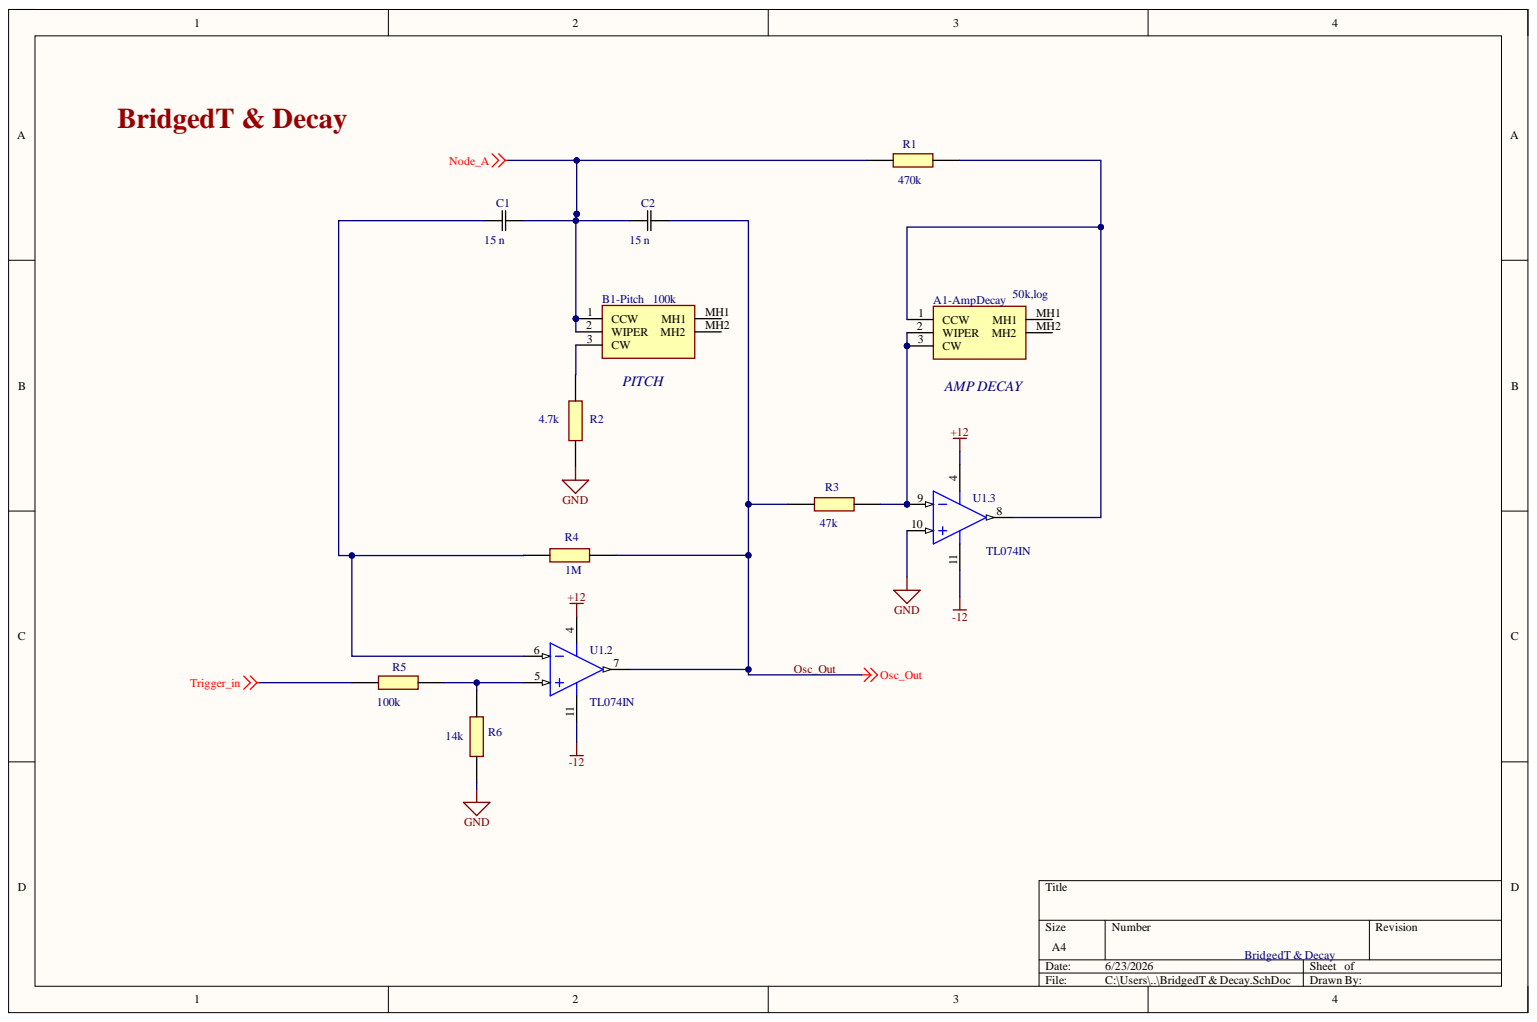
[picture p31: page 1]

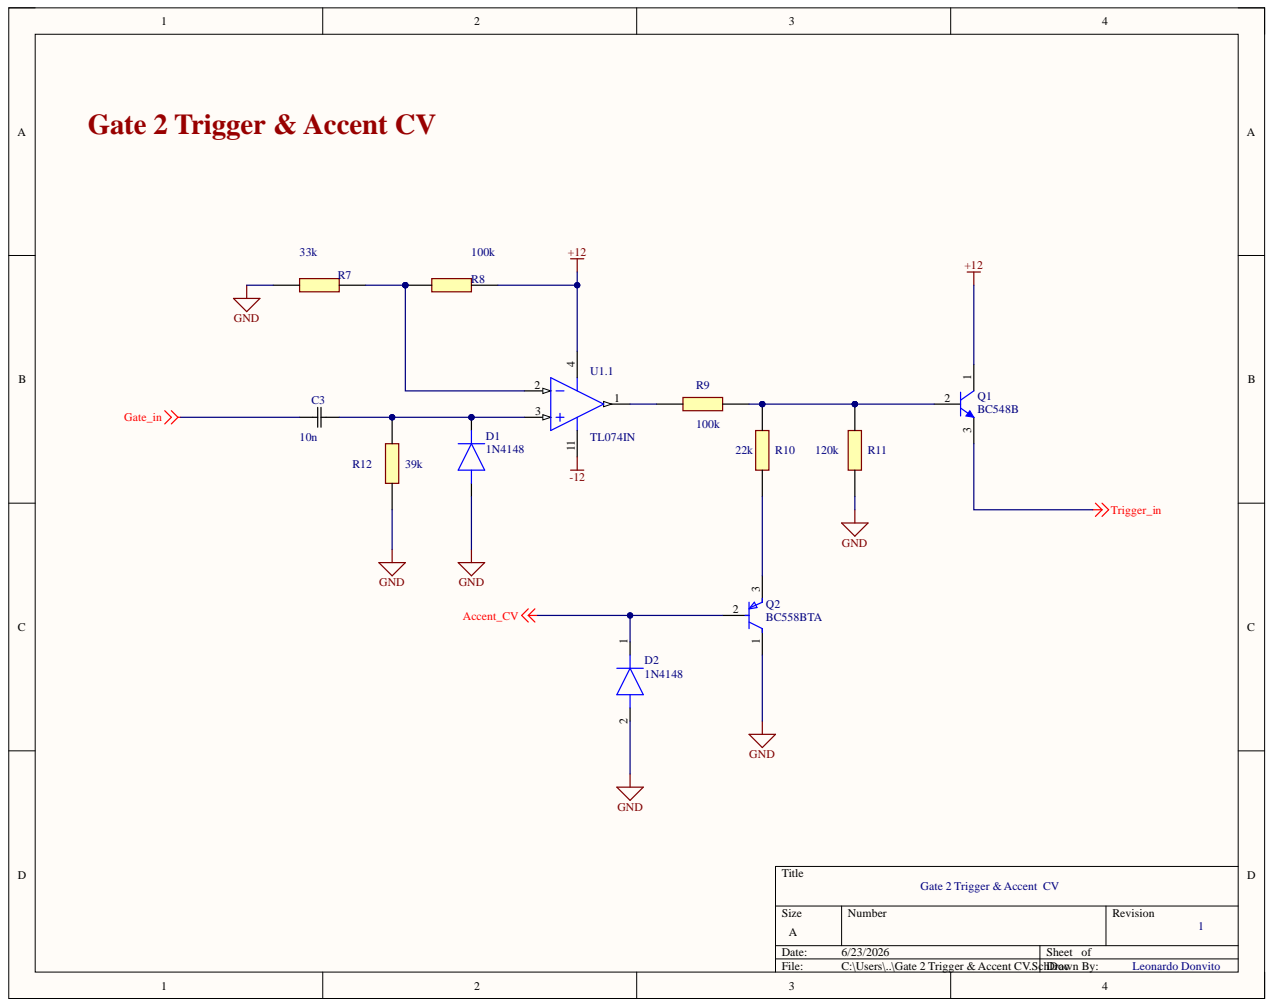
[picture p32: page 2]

Gate 2 Trigger & Accent CV

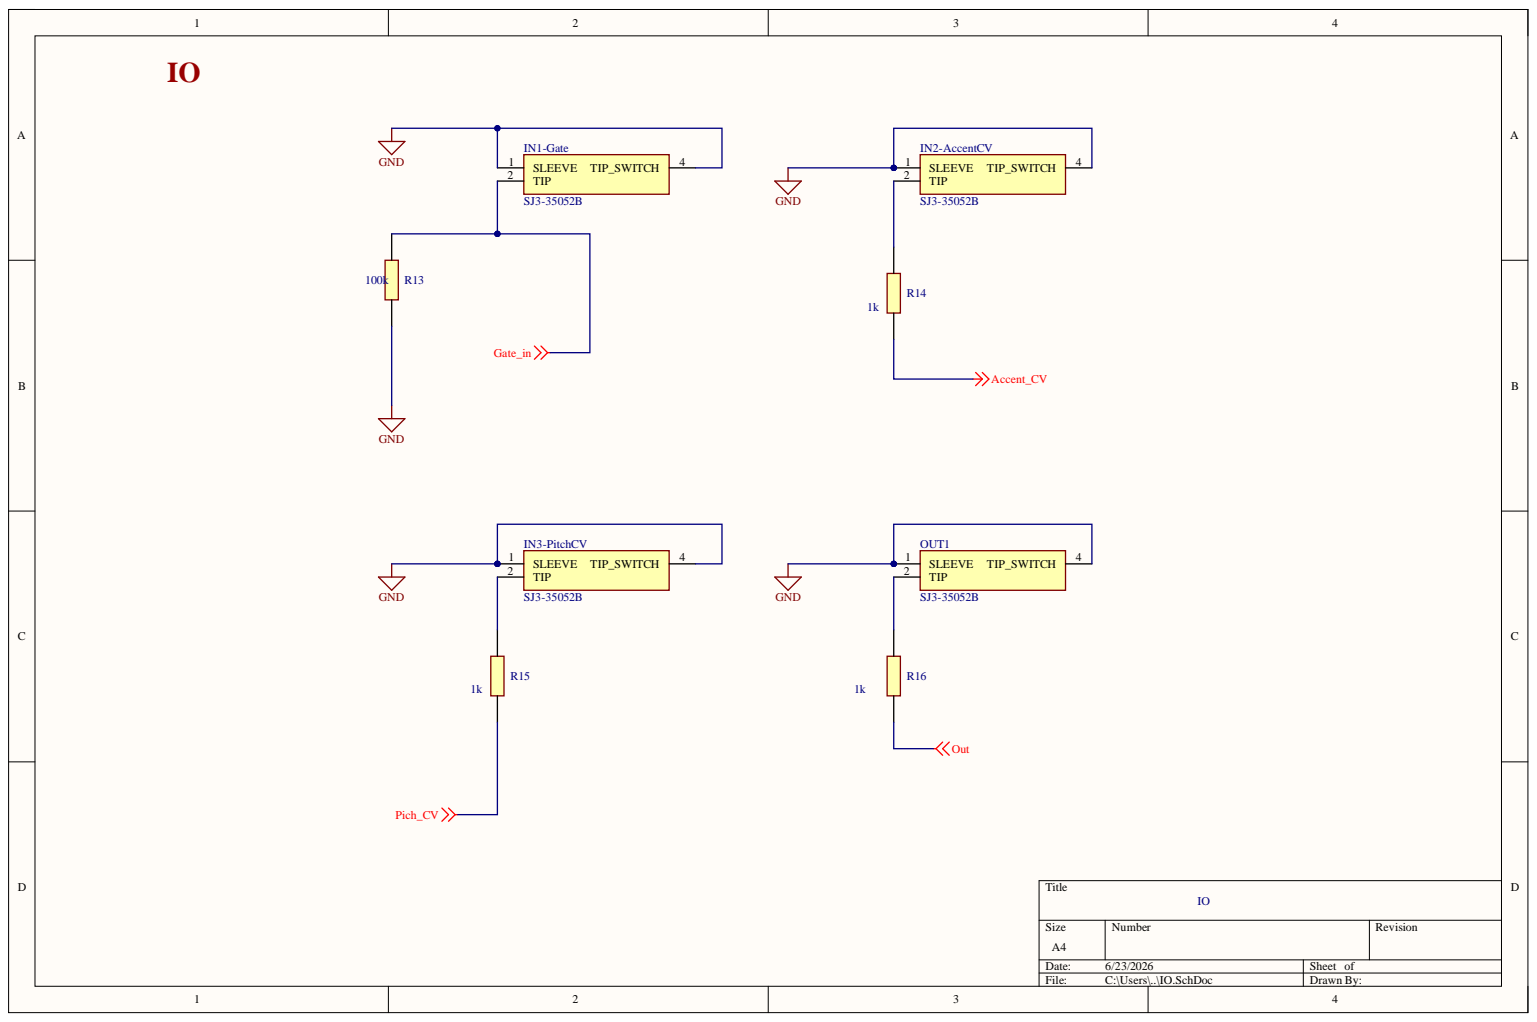
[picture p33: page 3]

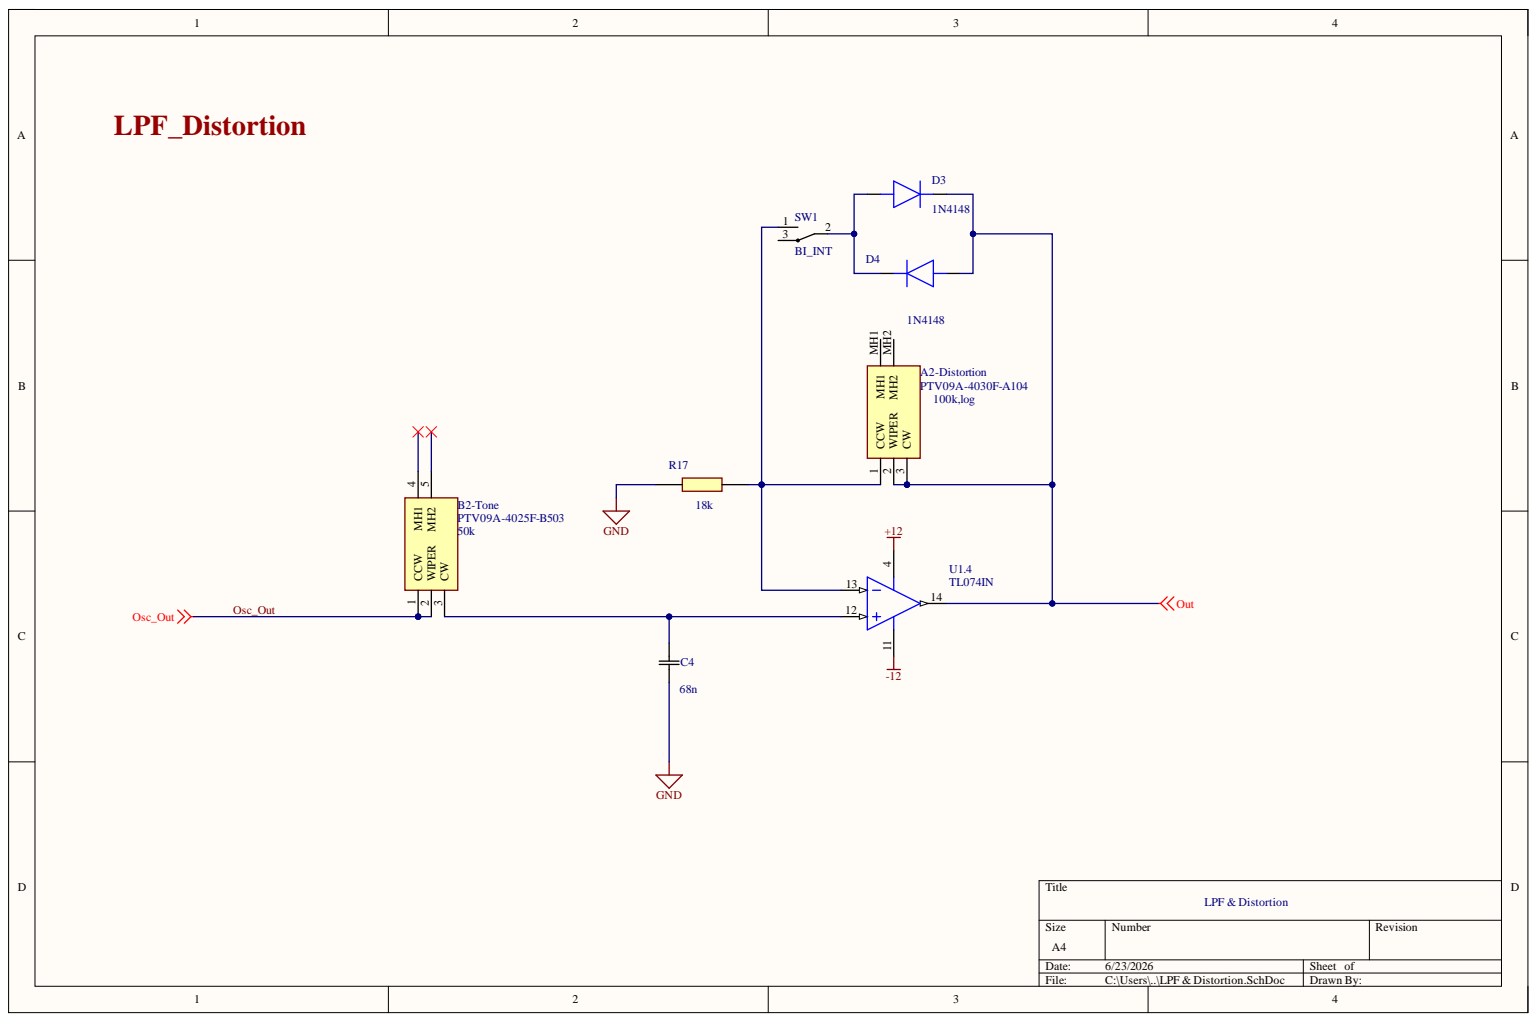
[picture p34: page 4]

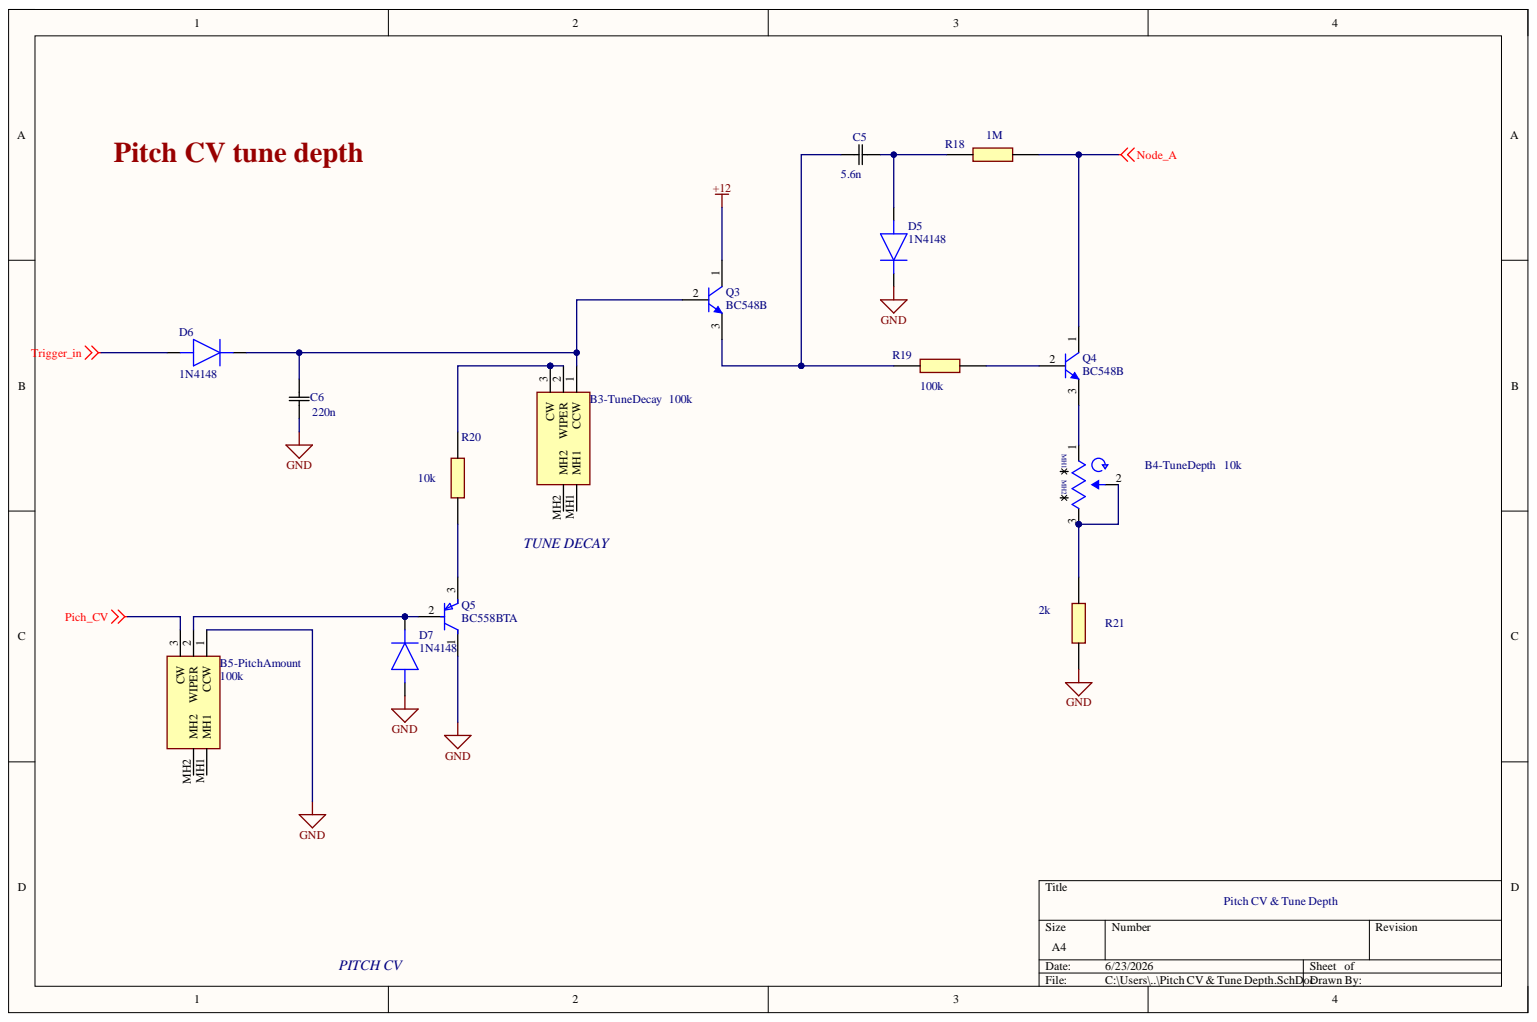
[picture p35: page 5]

Pitch CV tune depth

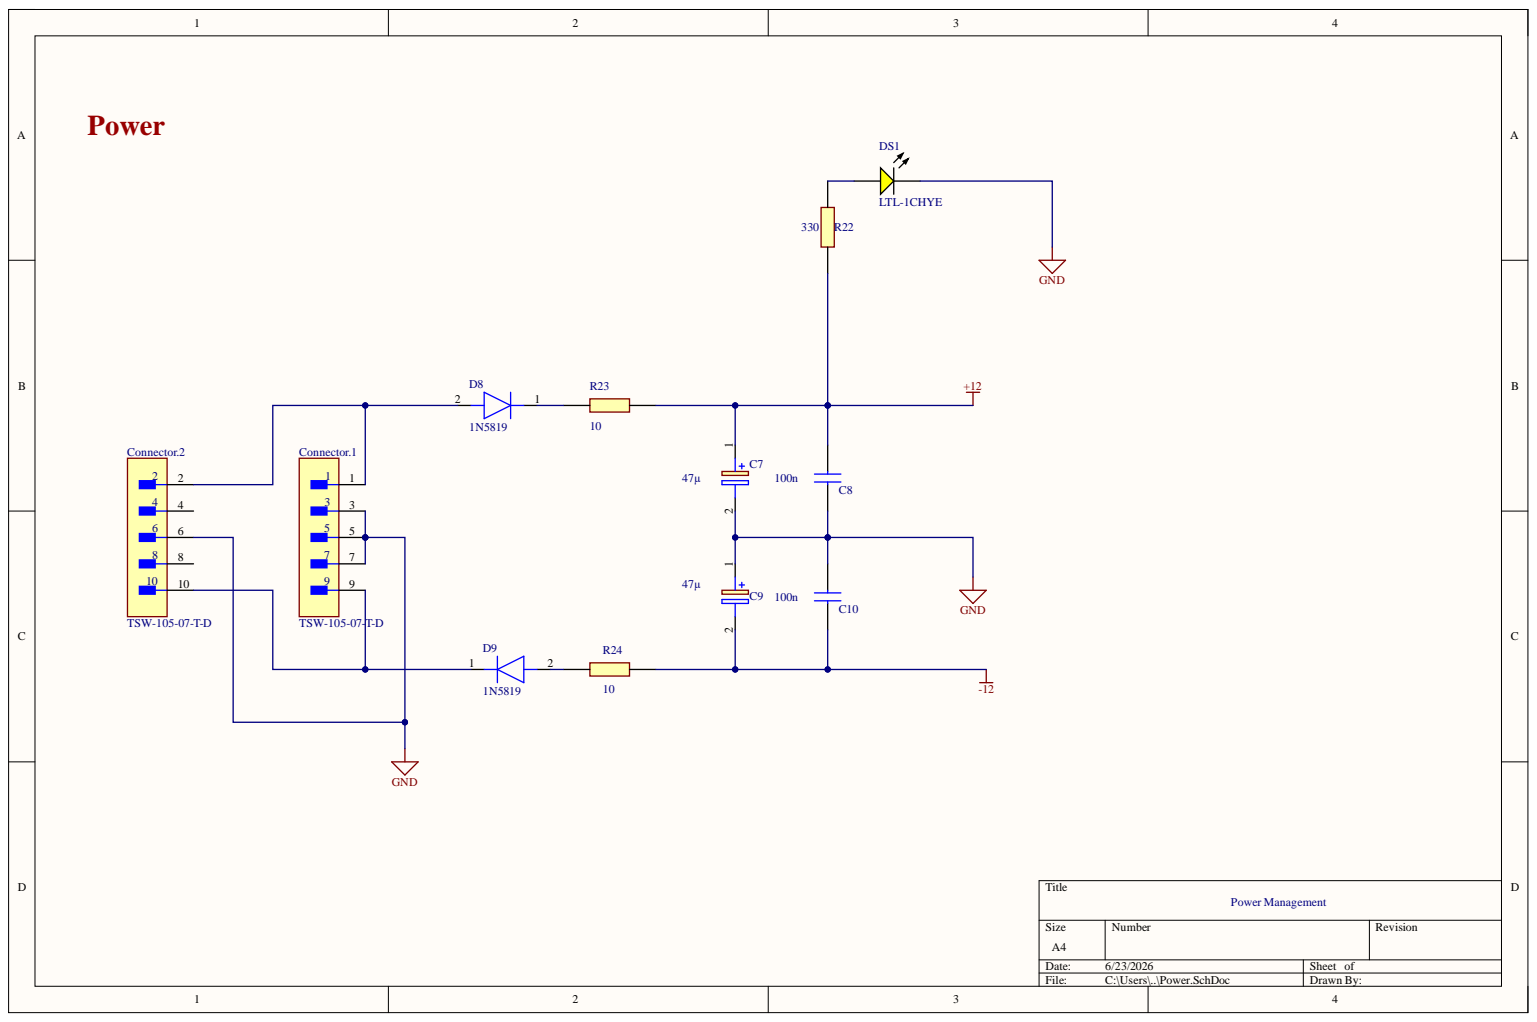
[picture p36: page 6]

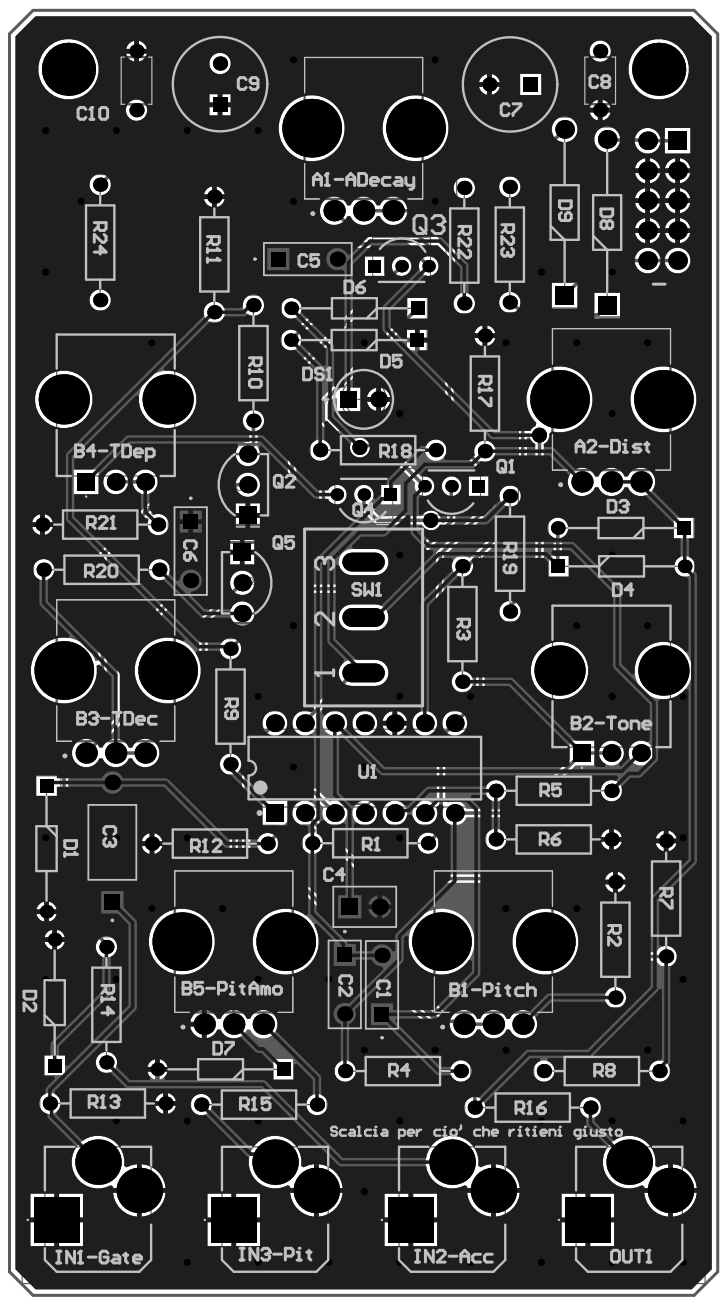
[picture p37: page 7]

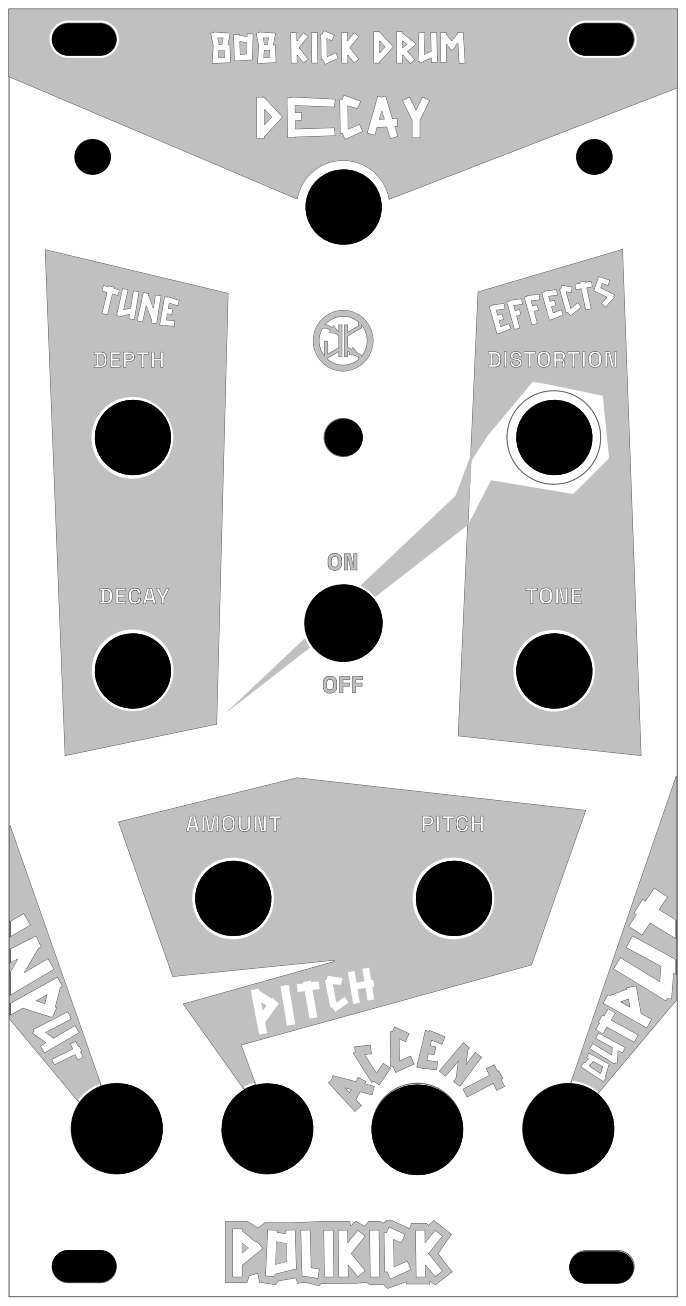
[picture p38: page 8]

Value | Part number | Line# | Description | Designator | Quantity
50k,log, 100k | PTV09A-4025F-B104 | | VariableResistor | A1-AmpDecay, B1-Pitch | 2
100k,log, 100k | PTV09A-4025F-B104 | 2 | VariableResistor | A2-Distortion, B3-TuneDecay, B5-PitchAmount | 3
50k | PTV09A-4025F-B103 | 19 | VariableResistor | B2-Tone | 1
10k | PTV09A-4025F-B103 | | 10k Ohm 1GangLinear Through Hole | B4-TuneDepth | 1
15n | MMK5153K50J01L4BULK | 3 | Condensatori a film 50volts 0.015uF10%LS5mm | C1, C2 | 2
10n | C430C106K3R5TA7200 | | 10nFceramic capacitor | C3 | 1
68n | C320C683J5R5TA | | 68nFceramic Capacitor | C4 | 1
5.6n | MMK5332K50J01L4BULK | | 3.3nFceramic capacitor- | C5 | 1
220n | MMK5224J50J01L4BULK | | 220nFfilm capacitor | C6 | 1
47µ | ESH476M050AG3KA | 8 | Suited for high quality | C7, C9 | 2
100n | K104K15X7RF5TH5 | 9 | VishayK104K15X7RF5TH5100nFMultilayer Ceramic Capacitor MLCC50Vdc +/-10% ToleranceThrough Hole | C8, C10 | 2
| TSW-105-07-T-D | 13 | TSW-105-07-T-DConn Unshrouded Header HDR10POS2.54mm Solder STThru-Hole AutomotiveBulk | Connector | 1
| 1N4148 | | Small Signal Diode | D1, D2, D3, D4, D5, D6, D7 | 7
| 1N5819 | 11 | Schottkybarrier diode,1N58191A40VSTMicroelectronics 1N5819 | D8, D9 | 2
| LTL-1CHYE | 12 | Through HoleLamp, 2.1V, -55to 100degC, 2-Pin THD, RoHS, Bulk | DS1 | 1
| SJ3-35052B | 1 | 3.5mm Stereo Jack | IN1-Gate, IN2-AccentCV, IN3-PitchCV, OUT1 | 4
| BC548B | | Bulk Through HoleNPN SingleBipolar (BJT) Transistor 200@2mA5V100mA500mW 300MHz | Q1, Q3, Q4 | 3
| BC558BTA | | BC558BTASmall Signal Bipolar Transistor, 0.1AI(C), 30VV(BR)CEO, 1-Element, PNP, Silicon, TO-92 | Q2, Q5 | 2
470k, 4.7k, 47k, 1M, 100k, 14k, 33k, 22k, 120k, 39k, 1k, 18k, 10k, 2k, 330, 10 | MFR-25FTF52-600K | 17 | Metal Film Resistors - Through Hole | R1, R2, R3, R4, R5, R6, R7, R8, R9, R10, R11, R12, R13, R14, R15, R16, R17, R18, R19, R20, R21, R22, R23, R24 | 24
| BI_INT | | ToggleSwitchesBUSHINGMOUNTMINIATURETOGGLE | SW1 | 1
| TL074IN | 21 | Quad Low-NoiseJFET-Input General-PurposeOperational Amplifier, 7to 36V, -40to 85 degC, 14-pin DIP(N14), Pb-Free(RoHS) | U1 | 1

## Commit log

2024-11-30 Pitch envelope non definitivo
    Rimane da capire esattamente come l'inviluppo sulla base del transistor modula la frequenza di oscillazione
2024-11-30 Cartella con sezioni BridgedT OSC
    Ho aggiunto la parte di pitch envelope, lì manca da capire come l'inviluppo sul transistor moduli la frequenza
2024-12-23 PoliKick Completo
    Schematico completo del PoliKick. Modifiche al Decay. Manca solo il distorsion stage di alessandro
2024-12-23 Delete spice/Pitch envelope (1).asc
    Non so che cosa ci facesse qui una verisone vecchia
2024-12-29 aggiunta cartella materiale
2025-01-05 aggiunto distorsore duro di lea
2025-02-14 pitch diventa da 100k con base da 4.7k, envelope da 50k
2025-02-14 stesso di prima
2025-02-25 Fix distortion stage
2025-02-25 Update full schematic with new distortion stage
2025-02-26 niente di che
2025-03-01 Update distortion stage
2026-05-05 updated Readme and Gerbers
2026-06-03 added front panel gerber step and dfx
    [PoliKick-rev2_3D.step, PoliKick-rev2_Scocca.DXF]
2026-06-18 Update Standoffs size in README
2026-06-23 Fix resistor part number in README
    Corrected the part number for the resistors in the README.
2026-06-23 updated schematics
2026-06-23 Add IC socket component to README
2026-06-23 updated gerbers
    [PoliKicK_PCB_rev-1.step, PoliKick_FrontPanel-rev1.step, PoliKick_FrontPanel_rev1.DXF]
2026-07-22 docs(manuals): caricata la documentazione i manuali utente e i datasheet ufficiali e aggiornato il readme di conseguenza
